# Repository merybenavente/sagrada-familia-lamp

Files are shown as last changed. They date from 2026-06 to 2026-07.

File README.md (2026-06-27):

# Sagrada Familia Lamp

Turn the lamps from the Sagrada Familia central tower inauguration into a smart nightstand light (or print your own Gaudí Lamp from scratch).

Context and hacking journey [on this thread](https://x.com/merybenavente/status/2065018276019589430). Thanks to [David Marcos](https://github.com/nozamdavid) for his central contributions to the 3D models.

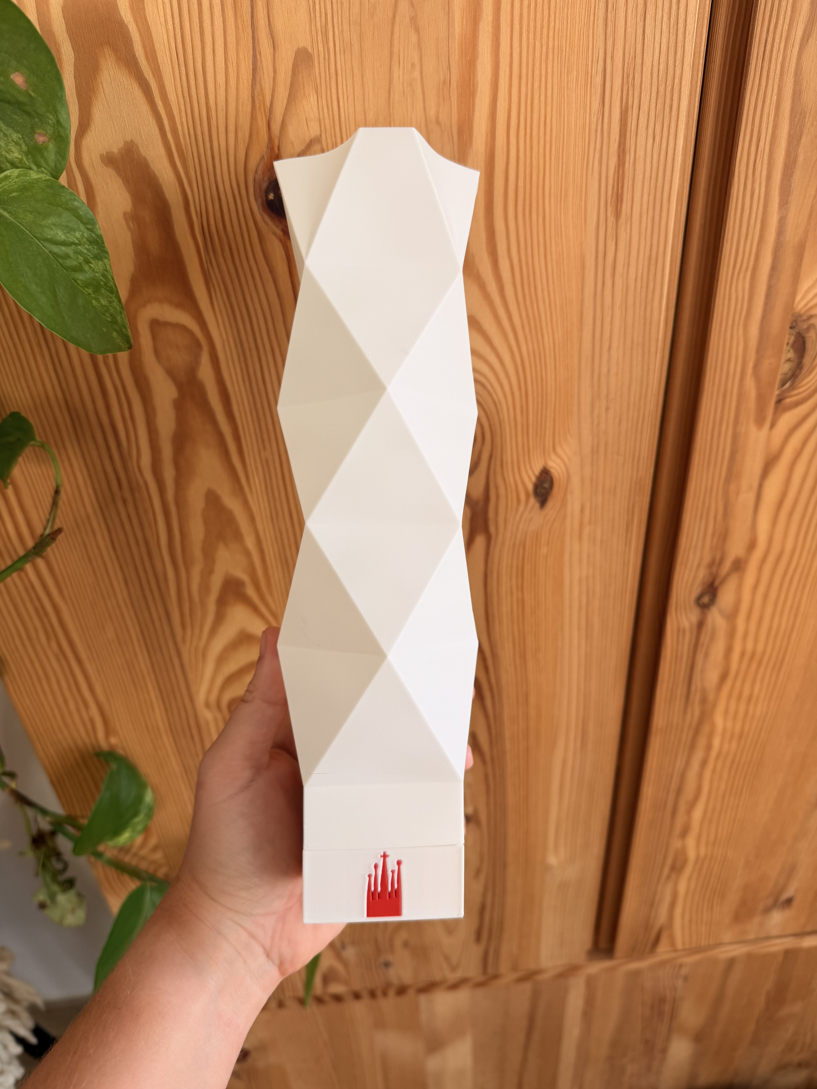
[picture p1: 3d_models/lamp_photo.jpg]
Sagrada Familia Lamp


## Projects

### 1. Hourly chime — make it glow every hour
Use an ESP32 + IR LED to fire a warm white fade effect at the top of every hour (I restricted mine 9am–10pm). The ESP32 syncs time via NTP once a day and deep-sleeps between chimes.

**What you need**
- The original PixMob lamp from the event
- ESP32: I bought one Seeed XIAO ESP32-C3, pre-soldered (~$11) for development and then Seeed XIAO ESP32-S3 unsoldered for assembling the final ones
- IR LED 940nm (emitter) — comes in packs (~$1)
- ~200Ω resistor (anything between 100–330Ω should work)
- 3.7V LiPo with JST connector (~500mAh is enough) (~$7)
- Breadboard + jumpers for prototyping (optional, but highly recommended)

**Wiring:** D10 → resistor → IR LED (+) → IR LED (−) → GND. For the LiPo battery, connect B+/B− pads to the XIAO pads (red +, black −).

**Setup:** flash [`hour_cue.ino`](hour_cue.ino) via the Arduino IDE (remember to update your WiFi credentials and timezone).

Now, every time your controller is near the lamp, it will chime on the clock!

### 2. IR remote with an on/off button
A physical button that toggles the lamp on and off via IR. The ESP32 deep-sleeps and wakes on button press.
[TODO include picture]

**What you need**
- The original PixMob lamp from the event
- Print the remote case (TODO add link)
- ESP32: I bought one Seeed XIAO ESP32-C3, pre-soldered (~$11) for development and then Seeed XIAO ESP32-S3 unsoldered for assembling the final ones
- IR LED 940nm (emitter) — comes in packs (~$1)
- ~200Ω resistor (anything between 100–330Ω should work)
- A button (the one compatible with the remote 3d on this repo is [this one](https://www.amazon.com/20pcs-Momentary-Tactile-Button-Switch/dp/B008DGA9UY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)) [TODO update with link to the specs instead of amazon]
- 3.7V LiPo with JST connector (~500mAh is enough) (~$7)
- Breadboard + jumpers for prototyping (optional, but highly recommended)

**Wiring:** D10 → One leg of the button → Diagonal Leg of that one → resistor → IR LED (+) → IR LED (−) → GND. For the LiPo battery, connect B+/B− pads to the XIAO pads (red +, black −).

**Setup:** flash [`remote.ino`](remote.ino) via the Arduino IDE.

### 3. Print your own lamp and include a smart light
If you want HomeKit / Siri control, the easier path is printing your own lamp and putting a smart bulb inside (simpler than trying to keep the original PixMob wired up).

I state the obvious: you will need to 3D print the lamp and put a smart light inside:
- The OpenSCAD source files are in [`3d_models/`](3d_models/), or grab the ready-to-print model on [MakerWorld](https://makerworld.com/en/models/2920312-tower-of-jesus-lamp-sagrada-familia-inauguration#profileId-3267552).
- For the light, you can use kits like the [Bambu Lab 3D lamp kit](https://us.store.bambulab.com/products/led-lamp-kit-001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) that come with a USB LED base — just print the shade and drop it on top.

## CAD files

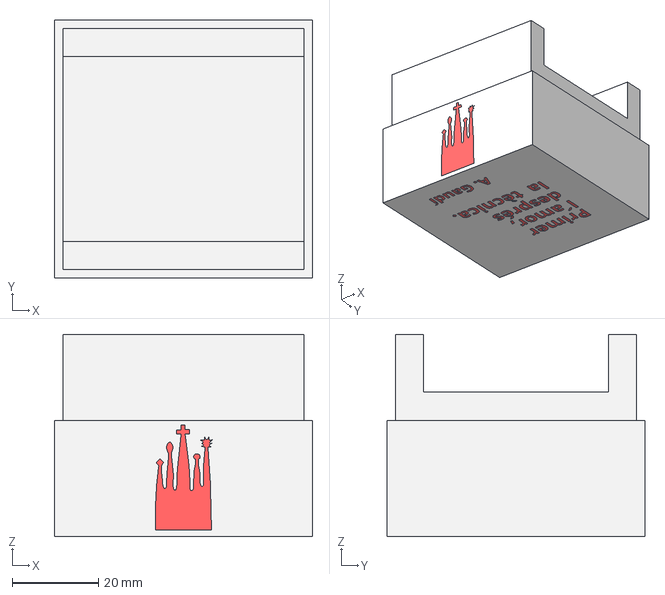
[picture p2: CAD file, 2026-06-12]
3d_models/lamp_base.step
60.0 x 60.0 x 47.0 mm

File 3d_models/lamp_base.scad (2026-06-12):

// ============================================
// Card Holder - Gaudí edition
// Dimensions: 60 x 50 x 40 mm
// Two side slots for sliding cards in
// "Primer l'amor..." quote in relief on front
// ============================================

// --- Main parameters ---
w = 60;          // width (X axis)
d = 50;          // depth (Y axis)
h = 40;          // total height (Z axis)
wall = 2.5;      // wall thickness
slot_w = 2.2;    // slot width (for ~0.8mm card + clearance)
slot_h = 35;     // slot height
slot_depth = 45; // how deep the slot goes (nearly full depth)
text_depth = 0.8;// text relief depth
chamfer = 3;     // top corner chamfer

// --- Main body ---
module body() {
    difference() {
        // Outer box
        cube([w, d, h]);

        // Inner cavity
        translate([wall, wall, wall])
            cube([w - 2*wall, d - 2*wall, h]);

        // Left slot (X=0)
        translate([-0.1, (d - slot_depth) / 2, h - slot_h])
            cube([wall + 0.2, slot_depth, slot_h + 0.1]);

        // Right slot (X=w)
        translate([w - wall - 0.1, (d - slot_depth) / 2, h - slot_h])
            cube([wall + 0.2, slot_depth, slot_h + 0.1]);
    }
}

// --- Relief text (front face, Y=0) ---
module front_text() {
    translate([w/2, text_depth, h * 0.42]) {
        rotate([90, 0, 0]) {
            // Line 1
            translate([0, 6, 0])
            linear_extrude(height = text_depth + 0.1)
                text("Primer l'amor,",
                     size = 5.5,
                     font = "Liberation Sans:style=Bold",
                     halign = "center",
                     valign = "center");
            // Line 2
            translate([0, -1, 0])
            linear_extrude(height = text_depth + 0.1)
                text("despres la tecnica.",
                     size = 5.5,
                     font = "Liberation Sans:style=Bold",
                     halign = "center",
                     valign = "center");
            // Signature
            translate([0, -9, 0])
            linear_extrude(height = text_depth + 0.1)
                text("A.Gaudi",
                     size = 5,
                     font = "Liberation Sans:style=Bold Italic",
                     halign = "center",
                     valign = "center");
        }
    }
}

// --- Final model ---
union() {
    body();
    front_text();
}

// ============================================
// PRINTING NOTES:
// - Orient with base facing down
// - Layer height: 0.15-0.2mm for good text detail
// - If using dual-color filament (multicolor/AMS):
//   text can be printed in red (Z pause at ~1mm)
// - Supports: not needed
// ============================================

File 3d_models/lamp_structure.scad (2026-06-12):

// ============================================
// Faceted column - Gaudí style
// Height: 240mm, fits 60x50mm base
// Solid, with waist, triangular facets
// ============================================

/* [Column] */
total_h   = 240;  // Total height (mm) [50:10:500]
base_w    = 55;   // Base width (mm) [10:1:150]
base_d    = 45;   // Base depth (mm) [10:1:150]
top_w     = 40;   // Top width (mm) [10:1:150]
top_d     = 33;   // Top depth (mm) [10:1:150]
waist_w   = 28;   // Waist width (mm) [10:1:150]
waist_d   = 23;   // Waist depth (mm) [10:1:150]
waist_pos = 0.42; // Waist position [0:0.01:1]
sections  = 24;   // Sections (more = smoother) [8:1:64]

/* [Base] */
plinth_w = 75;  // Base width (mm) [10:1:200]
plinth_d = 65;  // Base depth (mm) [10:1:200]
plinth_h = 8;   // Base height (mm) [2:1:30]

// --- Profile ---
function smooth(t) = t * t * (3 - 2 * t);

function profile_w(t) =
    t <= waist_pos
        ? base_w + (waist_w - base_w) * smooth(t / waist_pos)
        : waist_w + (top_w - waist_w) * smooth((t - waist_pos) / (1 - waist_pos));

function profile_d(t) =
    t <= waist_pos
        ? base_d + (waist_d - base_d) * smooth(t / waist_pos)
        : waist_d + (top_d - waist_d) * smooth((t - waist_pos) / (1 - waist_pos));

module faceted_column() {
    for (i = [0 : sections - 1]) {
        t0 = i / sections;
        t1 = (i + 1) / sections;
        z0 = t0 * total_h;
        z1 = i == sections -1 ? (t1 * total_h)+20    : t1 * total_h;
        w0 = profile_w(t0) / 2;
        d0 = profile_d(t0) / 2;
        w1 = profile_w(t1) / 2;
        d1 = profile_d(t1) / 2;

        // Alternating rotation for diamond/facet effect
        rot0 = (i % 2 == 0) ? 0 : 45;
        rot1 = (i % 2 == 0) ? 45 : 0;

        hull() {
            translate([0, 0, z0])
                rotate([0, 0, rot0])
                    scale([w0, d0, 1])
                        cylinder(h = 0.01, r = 1, $fn = 4);

            translate([0, 0, z1])
                rotate([0, 0, rot1])
                    scale([w1, d1, 1])
                        cylinder(h = 0.01, r = 1, $fn = 4);
        }
    }
}

module square_base() {
    hw = plinth_w / 2;
    hd = plinth_d / 2;
    translate([0, 0, -plinth_h])
        linear_extrude(height = plinth_h)
            polygon([[hw,0],[0,hd],[-hw,0],[0,-hd]]);
}

// --- Render ---
square_base();
faceted_column();

// ============================================
// NOTES:
// - Base: ~55x45mm -> fits 60x50mm box
// - Print vertically (base down)
// - Layer height: 0.2mm, 15% infill is enough
// - No supports needed
// - To adjust the waist: change waist_pos
//   (0.3 = lower, 0.5 = exact center)
// ============================================

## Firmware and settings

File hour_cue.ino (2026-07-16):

#include <WiFi.h>
#include <time.h>
#include <IRremoteESP8266.h>
#include <IRsend.h>

// ---------- CONFIG: fill in your WiFi ----------
const char* WIFI_SSID = "YOUR_WIFI_NAME";
const char* WIFI_PASS = "YOUR_WIFI_PASSWORD";

const char* TZ_INFO = "CET-1CEST,M3.5.0,M10.5.0/3";  // Barcelona. New York: "EST5EDT,M3.2.0,M11.1.0"
// -----------------------------------------------

IRsend irsend(9);  // D10 on XIAO ESP32S3 = GPIO 9

uint16_t WARM_WHITE[] = {
  700,1400,1400,700,700,700,1400,2800,700,1400,700,700,700,2100,700,1400,1400,
  1400,700,2100,700,2800,700,1400,700,700,1400,700,700,700,700,700,700,1400,700,
  1400,700,2800,700
};
const uint16_t LEN = sizeof(WARM_WHITE) / sizeof(WARM_WHITE[0]);

void fireEffect() {
  irsend.begin();
  for (int i = 0; i < 3; i++) {
    irsend.sendRaw(WARM_WHITE, LEN, 38);
    delay(200);
  }
}

bool syncNTP() {
  WiFi.begin(WIFI_SSID, WIFI_PASS);
  unsigned long start = millis();
  while (WiFi.status() != WL_CONNECTED && millis() - start < 15000) delay(250);
  if (WiFi.status() != WL_CONNECTED) {
    WiFi.mode(WIFI_OFF);
    return false;
  }
  configTzTime(TZ_INFO, "pool.ntp.org", "time.nist.gov");
  struct tm t;
  bool ok = getLocalTime(&t, 10000);
  WiFi.disconnect(true);
  WiFi.mode(WIFI_OFF);
  return ok;
}

void setup() {
  setenv("TZ", TZ_INFO, 1);
  tzset();

  // Sync real time every wake via NTP
  if (!syncNTP()) {
    // No WiFi, retry in 5 min
    esp_sleep_enable_timer_wakeup(300ULL * 1000000ULL);
    esp_deep_sleep_start();
  }

  struct tm now;
  time_t t = time(NULL);
  localtime_r(&t, &now);

  // Fire if within 2 minutes of the hour (before or after)
  if (now.tm_min <= 1 || now.tm_min >= 59) fireEffect();

  // Sleep until next hour
  int secsToNext = 3600 - (now.tm_min * 60 + now.tm_sec);
  if (secsToNext < 60) secsToNext += 3600;
  esp_sleep_enable_timer_wakeup((uint64_t)secsToNext * 1000000ULL);
  esp_deep_sleep_start();
}

void loop() {}

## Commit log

2026-06-11 First draft: replica of the lamps from the Sagrada Familia inauguration event (by Claude)
    OpenSCAD models replicating the lamps used at the Sagrada Familia
    central tower inauguration ceremony:
    - lamp_base: base with Gaudí quote in relief
    - lamp_structure: faceted column structure
    🤖 First draft generated with Claude Code — PRs welcome!
    [lamp_base.scad, lamp_structure.scad]
2026-06-11 Add README with project context and link to thread
2026-06-11 Update README: link text for thread
2026-06-11 add lamp base step file and improved lamp scad
    [lamp_base.scad, lamp_base.step, lamp_structure.scad]
2026-06-12 Translate all comments to English
    [lamp_base.scad, lamp_structure.scad]
2026-07-16 fix hour_cue: sync NTP every wake, fix GPIO pin for XIAO S3
    Simplify hour_cue to sync real time via NTP on every wake instead of
    relying on RTC-estimated time that drifts. Fire if within 2 minutes
    of the hour. Fix IR pin to GPIO 9 (D10 on XIAO ESP32S3). Run 24h
    instead of 9-22 window.
    [hour_cue.ino]
